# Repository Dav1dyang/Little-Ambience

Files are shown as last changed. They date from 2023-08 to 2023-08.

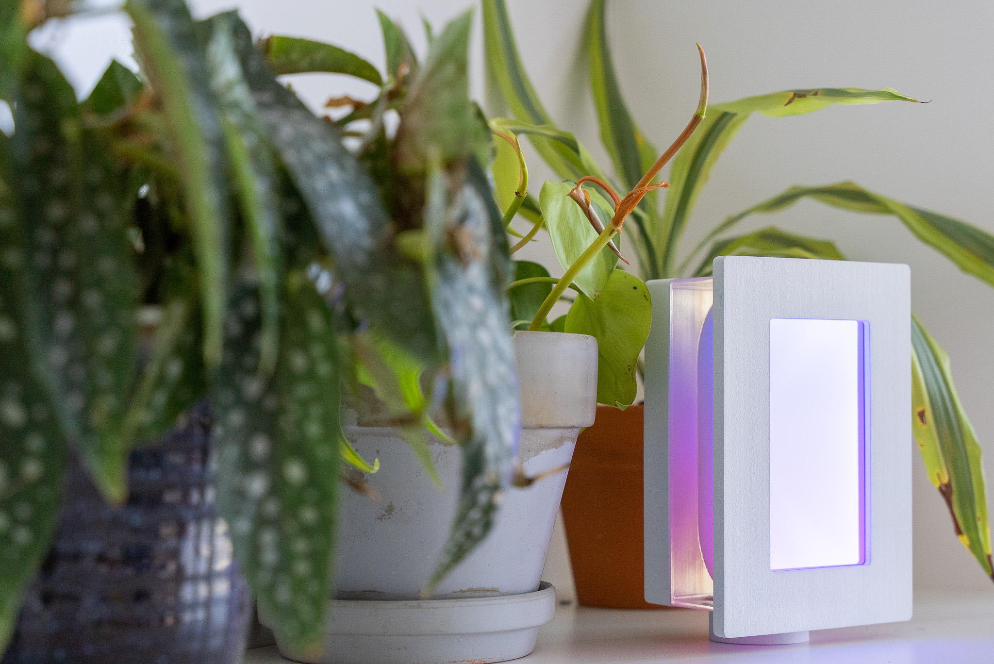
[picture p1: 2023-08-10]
Photos/Product1-Day_and_Night.jpg

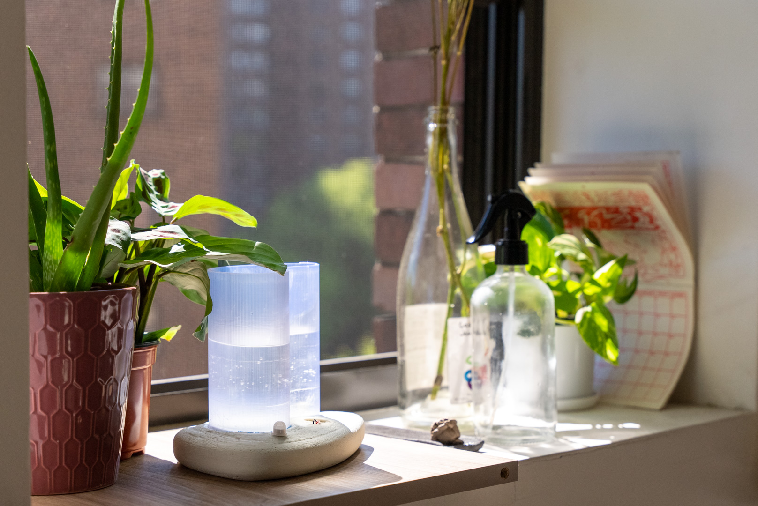
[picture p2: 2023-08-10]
Photos/Water_and_Air_Side.jpg

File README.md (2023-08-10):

# Little Ambience

Tabletop_light

A series of speculative products designed by David Yang. For more information, please visit: https://davidyang.work/Little-Ambience-Detail

## Intro

Little Ambience is a series of speculative household electronics that simulate the remote presence of people and places without relying on video calls. The series comprises two electronics: a tabletop/wall mount light and a pair of humidifiers. The light, designed to resemble a window, displays the sky from a location where people feel connected. The humidifiers are placed in different locations or homes and activate only when both sense the presence of people in the space.

Little Ambience takes the simulation of nature and senses, such as light and smell, to gently decorate a living space with a presence of a place or a person we care about and love. Mirroring the form it takes, Little Ambience interacts passively.

The form is inspired by Taiwanese architectural textures such as pressed windows and Terrazzo, as well as the space and light sculptures made by James Turrell.

## Code

The code is only for functionality testing. It is made specifically to run on ESP32 and a custom PCB.

Right now, the code provided will be able to test out the gradient lights function for the Day & Night light and the mist trigger for the Water & Air humidifier. A few critical steps still need to be taken for it actually to work (Looking for developers to collab!).

Here are the functions list:

### Day and Night (TableTop Light)

| Function | Done? |
| --- | ----- |
| Gradient Color Test | Yes |
| 24 hours sky color test | No |
| ESP32 WIFI Connection | No |
| Weather API Integration | No |
| Weather Animations | No |
| Audio Intergration | No |
| Backend Server | No |

### Water and Air (Humidifier)

| Function | Done? |
| --- | ----- |
| Mist Trigger Test | Yes |
| PIR Sensor Test | No |
| ESP32 WIFI Connection | No |
| Backend server | No |

I used chroma.js with glitch to host a simple server to generate gradient values: https://glitch.com/edit/#!/little-ambience-server

## Little Ambience PCB V1.1

This PCB design utilizes its small footprint to fit into the product. It uses JST connectors for NeoPixels and Lipo Battery. It has USB Mirco for charging.

## Next Steps

I will work on this project's code as much as I can. But I would love to seek help from a professional coder. Moreover, I want to set up live cameras pointing at the sky and find a way to map the sky to Day and Night light.

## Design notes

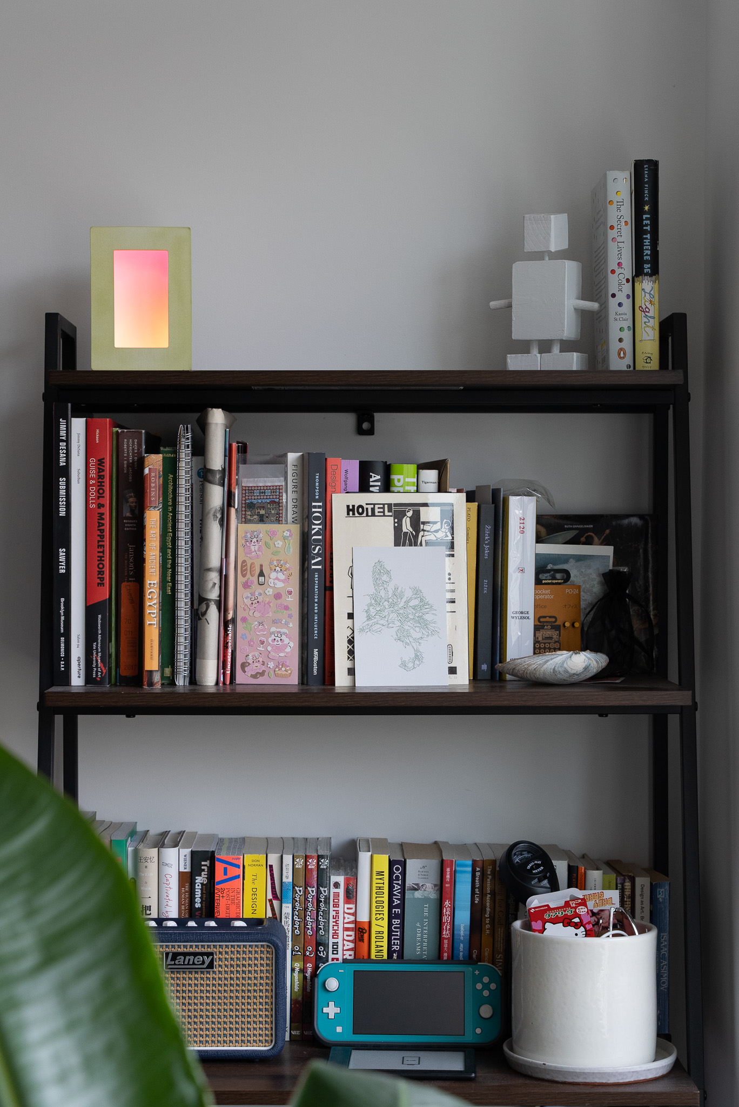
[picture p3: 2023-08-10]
Photos/Day_and_Night_Green_Front.jpg

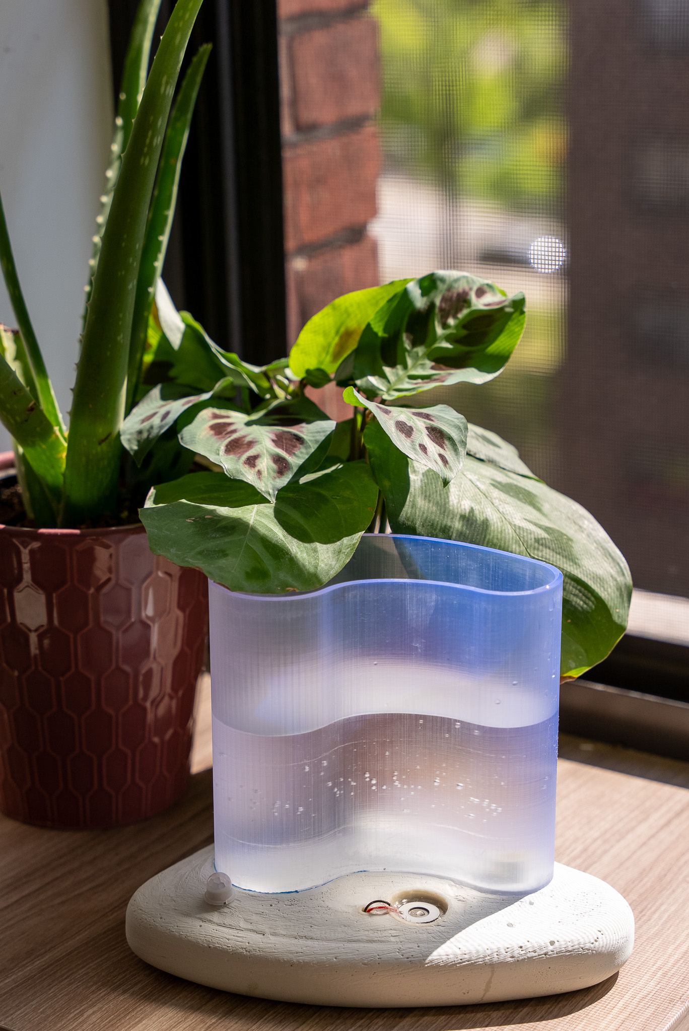
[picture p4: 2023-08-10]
Photos/Product2-Water_and_Air.jpg

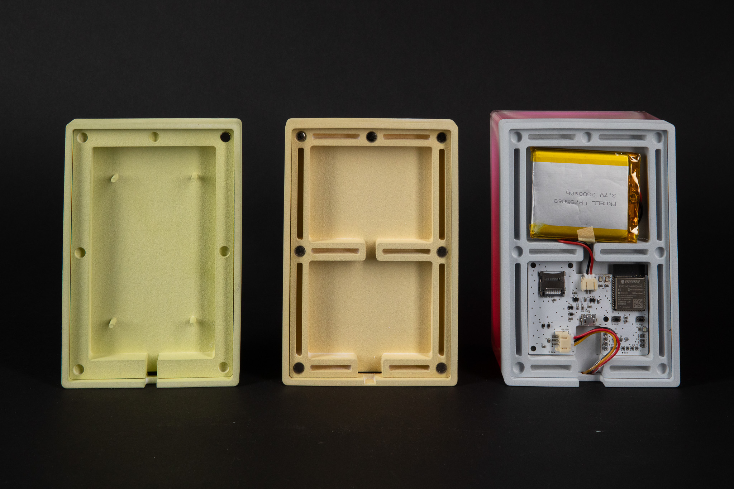
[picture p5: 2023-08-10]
Photos/Day_and_Night_Process_Back.jpg

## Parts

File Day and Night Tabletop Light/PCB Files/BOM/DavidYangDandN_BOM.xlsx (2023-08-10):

Comment | Designator | Footprint | JLCPCB Part #（optional）
0.1uf | C3 | CAPC1608X85 | C386152
10118192-0001LF | USB_MICRO | 10118192-0001LF | C132564
10K | R5, R8, R15, R16 | RESC1608X60 | C227439
10uf | C2, C4 | CAPC1608X85 | C307460
1A/23V/620mV | D2 | SOD-323 | C155590
1uf | C1, C8 | CAPC1608X85 | C106858
2.0k | R2 | RESC1608X60 | C160602
2.2uf | C9 | CAPC1608X85 | C92760
20V/4.2A/52mΩ/1.4W | Q1 | SOT23-3 | C150470
3.3V | IC3 | SOT23-5 | C3021085
470 Ohm | R3, R4, R6, R7 | RESC1608X60 | C175657
5.1K | R1 | RESC1608X60 | C218090
560K | R9 | RESC1608X60 | C137699
AO3406-HT | Q2 | SOT95P280X125-3N | C88051
ESP32-S3-WROOM-1-N8R8 | IC1 | ESP32S3WROOM1N8R8 | C2913201
HYC39-TF08-180 | MICROSD_READER | HYC39TF08180 | C341095
IC_LIPO_CHARGER | IC2 | SOT23-5 | C424093
KMR221NGLFS | S1_BOOT, S2_RESET | KMR221NGLFS | C269272
LTST-C170KFKT | LED1, LED_DONE | LEDC2012X120N | C284931
LTST-C170TBKT | LED_CHARGE | LEDC2012X120N | C98222
PMEG2020AEA,115 | D1, D3 | SOD2512X110N | C389354
S2B-PH-SM4-TB_LF__SN_ | CN2_BAT | S2BPHSM4TBLFSN | C295747
S3B-PH-SM4-TB_LF__SN_ | CN1_NEO | S3B-PH-SM4-TB | C265101

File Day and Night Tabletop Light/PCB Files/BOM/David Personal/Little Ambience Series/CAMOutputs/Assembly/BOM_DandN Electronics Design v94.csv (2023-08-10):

Qty | Value | Device | Package | Parts | Description | ARROW_PART_NUMBER | ARROW_PRICE-STOCK | CATEGORY | DESCRIPTION | HEIGHT | MANUFACTURER | MANUFACTURER_NAME | MANUFACTURER_PART_NUMBER | MOUSER_PART_NUMBER | MOUSER_PRICE-STOCK | MPN | OPERATING_TEMP | PART_STATUS | PROD_ID | RATING | ROHS_COMPLIANT | SERIES | SUB-CATEGORY | THERMALLOSS | TOLERANCE | TYPE | VALUE | VOLTAGE_RATING
1 |  | CONN_02 | 1X02 | CN4_SWITCH | Multi connection point. Often used as Generic Header-pin footprint for 0.1 inch spaced/style header connections
1 |  | CONN_03LONGPADS | 1X03_LONGPADS | CN5_POWER | Multi connection point. Often used as Generic Header-pin footprint for 0.1 inch spaced/style header connections
1 |  | CONN_04 | 1X04 | CN6_PIR | Multi connection point. Often used as Generic Header-pin footprint for 0.1 inch spaced/style header connections |  |  |  |  |  |  |  |  |  |  |  |  |  | CONN-09696
1 |  | CONN_05 | 1X05 | CN3_I2S | Multi connection point. Often used as Generic Header-pin footprint for 0.1 inch spaced/style header connections
1 | 0.1uf | C_CHIP-0603(1608-METRIC) | CAPC1608X85 | C3 | Capacitor - Generic |  |  | Capacitor
1 | 10118192-0001LF | 10118192-0001LF | 10118192-0001LF | USB_MICRO | USB - micro B USB 2.0 Receptacle Connector 5 Position Surface Mount, Right Angle |  |  |  | USB - micro B USB 2.0 Receptacle Connector 5 Position Surface Mount | Right Angle | mm |  | Digi-Key Electronics | 10118192-0001LF
4 | 10K | R_CHIP-0603(1608-METRIC) | RESC1608X60 | R5, R8, R15, R16 | Resistor Fixed - Generic |  |  | Resistor |  |  |  |  |  |  |  |  |  |  |  |  |  |  | Fixed
2 | 10uf | C_CHIP-0603(1608-METRIC) | CAPC1608X85 | C2, C4 | Capacitor - Generic |  |  | Capacitor
1 | 1A/23V/620mV | DIODE-SCHOTTKY-BAT20J | SOD-323 | D2 | Schottky diode |  |  |  |  |  |  |  |  |  |  |  |  |  | DIO-11623 |  |  |  |  |  |  |  | 1A/23V/620mV
2 | 1uf | C_CHIP-0603(1608-METRIC) | CAPC1608X85 | C1, C8 | Capacitor - Generic |  |  | Capacitor
1 | 2.0k | R_CHIP-0603(1608-METRIC) | RESC1608X60 | R2 | Resistor Fixed - Generic |  |  | Resistor |  |  |  |  |  |  |  |  |  |  |  |  |  |  | Fixed
1 | 2.2uf | C_CHIP-0603(1608-METRIC) | CAPC1608X85 | C9 | Capacitor - Generic |  |  | Capacitor
1 | 20V/4.2A/52mΩ/1.4W | MOSFET_PCH-DMG2305UX-7 | SOT23-3 | Q1 | P-channel MOSFETs |  |  |  |  |  |  |  |  |  |  |  |  |  | TRAN-14388 |  |  |  |  |  |  |  | 20V/4.2A/52mΩ/1.4W
1 | 3.3V | V_REG_AP2112K-3.3V | SOT23-5 | IC3 | AP2112 - 600mA CMOS LDO Regulator w/ Enable |  |  |  |  |  |  |  |  |  |  |  |  |  | VREG-12457 |  |  |  |  |  |  |  | 3.3V
4 | 470 Ohm | R_CHIP-0603(1608-METRIC) | RESC1608X60 | R3, R4, R6, R7 | Resistor Fixed - Generic |  |  | Resistor |  |  |  |  |  |  |  |  |  |  |  |  |  |  | Fixed
1 | 5.1K | R_CHIP-0603(1608-METRIC) | RESC1608X60 | R1 | Resistor Fixed - Generic |  |  | Resistor |  |  |  |  |  |  |  |  |  |  |  |  |  |  | Fixed
1 | 560K | R_CHIP-0603(1608-METRIC) | RESC1608X60 | R9 | Resistor Fixed - Generic |  |  | Resistor |  |  |  |  |  |  |  |  |  |  |  |  |  |  | Fixed
1 | AO3406-HT | AO3406-HT | SOT95P280X125-3N | Q2 | 30V N-Channel MOSFET |  |  |  | 30V N-Channel MOSFET | 1.25mm |  | Alpha & Omega Semiconductors | AO3406-HT
1 | ESP32-S3-WROOM-1-N8R8 | ESP32-S3-WROOM-1-N8R8 | ESP32S3WROOM1N8R8 | IC1 | WiFi Modules - 802.11 (Engineering Samples Only) SMD Module, ESP32-S3R8 with 8 MB Octal PSRAM Die, 8 MB Quad SPI flash, PCB Antenna |  |  |  | WiFi Modules - 802.11 (Engineering Samples Only) SMD Module | ESP32-S3R8 with 8 MB Octal PSRAM Die | 8 MB Quad SPI flash | PCB Antenna | 3.25mm |  | Espressif Systems | ESP32-S3-WROOM-1-N8R8 | 356-EP32S3WROOM1N8R8 | https://www.mouser.co.uk/ProductDetail/Espressif-Systems/ESP32-S3-WROOM-1-N8R8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
1 | HYC39-TF08-180 | HYC39-TF08-180 | HYC39TF08180 | MICROSD_READER | Connector SIM CardSD Memory Card 8 SMD Card Sockets Connectors ROHS |  |  |  | Connector SIM CardSD Memory Card 8 SMD Card Sockets Connectors ROHS | 2.1mm |  | HOAUC | HYC39-TF08-180
1 | IC_LIPO_CHARGER | IC_LIPO_CHARGER | SOT23-5 | IC2 | MCP73831/2: LiPo Battery Charger
2 | KMR221NGLFS | KMR221NGLFS | KMR221NGLFS | S1_BOOT, S2_RESET | KMR221NGLFS (Tactile Switches) |  |  |  | KMR221NGLFS (Tactile Switches) | 1.9mm |  | C & K COMPONENTS | KMR221NGLFS | 611-KMR221NGLFS | https://www.mouser.co.uk/ProductDetail/CK/KMR221NGLFS?qs=sb%252But3Lm4x2H4qewmcuXNA%3D%3D
2 | LTST-C170KFKT | LTST-C170KFKT | LEDC2012X120N | LED1, LED_DONE | Standard LEDs - SMD Orange Clear 605nm | LTST-C170KFKT | https://www.arrow.com/en/products/ltst-c170kfkt/lite-on-technology?region=nac |  | Standard LEDs - SMD Orange Clear 605nm | 1.2mm |  | Lite-On | LTST-C170KFKT | 859-LTST-C170KFKT | https://www.mouser.co.uk/ProductDetail/Lite-On/LTST-C170KFKT?qs=gKd32bbgGM%2FWUWN9MKaKoA%3D%3D
1 | LTST-C170TBKT | LTST-C170TBKT | LEDC2012X120N | LED_CHARGE | LED,SMD,0805,Blue,28mcd,130deg | LTST-C170TBKT | https://www.arrow.com/en/products/ltst-c170tbkt/lite-on-technology?region=nac |  | LED | SMD | 0805 | Blue | 28mcd | 130deg | 1.2mm |  | Lite-On | LTST-C170TBKT | 859-LTST-C170TBKT | https://www.mouser.co.uk/ProductDetail/Lite-On/LTST-C170TBKT?qs=0uL0gcxEMop2ooGmIUzw3A%3D%3D
2 | PMEG2020AEA,115 | PMEG2020AEA,115 | SOD2512X110N | D1, D3 | NXP PMEG2020AEA,115, SMT Schottky Diode, 20V 2A, 2-Pin SOD-323 | PMEG2020AEA | 115 | https://www.arrow.com/en/products/pmeg2020aea115/nexperia?region=nac |  | NXP PMEG2020AEA | 115 | SMT Schottky Diode | 20V 2A | 2-Pin SOD-323 | 1.1mm |  | Nexperia | PMEG2020AEA | 115 | 771-PMEG2020AEA-T/R | https://www.mouser.co.uk/ProductDetail/Nexperia/PMEG2020AEA115?qs=LOCUfHb8d9vXteLLZxwsEQ%3D%3D
1 | S2B-PH-SM4-TB_LF__SN_ | S2B-PH-SM4-TB_LF__SN_ | S2BPHSM4TBLFSN | CN2_BAT | Conn Shrouded Header (4 Sides) HDR 2 POS 2mm Solder RA Side Entry SMD T/R | S2B-PH-SM4-TB(LF)(SN) | https://www.arrow.com/en/products/s2b-ph-sm4-tb-lf-sn/jst-manufacturing?region=europe |  | Conn Shrouded Header (4 Sides) HDR 2 POS 2mm Solder RA Side Entry SMD T/R | 6.6mm |  | JST (JAPAN SOLDERLESS TERMINALS) | S2B-PH-SM4-TB(LF)(SN)
1 | S3B-PH-SM4-TB_LF__SN_ | S3B-PH-SM4-TB_LF__SN_ | S3B-PH-SM4-TB | CN1_NEO | PH SMT side entry shroud header 3 way JST PH Series, 2mm Pitch 3 Way 1 Row Right Angle PCB Header, Solder Termination, 2A | S3B-PH-SM4-TB(LF)(SN) | https://www.arrow.com/en/products/s3b-ph-sm4-tb-lf-sn/jst-manufacturing?region=europe |  | PH SMT side entry shroud header 3 way JST PH Series | 2mm Pitch 3 Way 1 Row Right Angle PCB Header | Solder Termination | 2A | mm |  | JST (JAPAN SOLDERLESS TERMINALS) | S3B-PH-SM4-TB(LF)(SN)

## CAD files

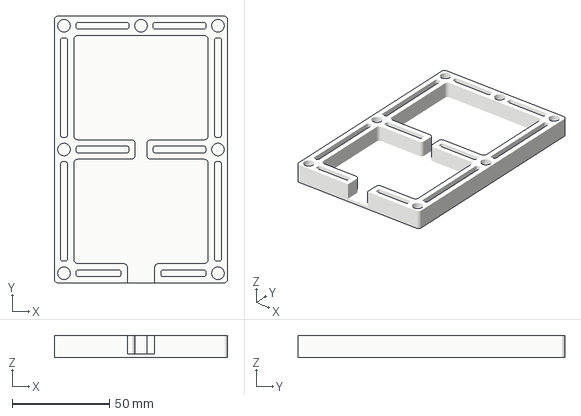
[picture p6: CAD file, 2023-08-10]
Day and Night Tabletop Light/3D Prints/DandN Version 4_Back_Panel.3mf
89.0 x 137.0 x 11.4 mm

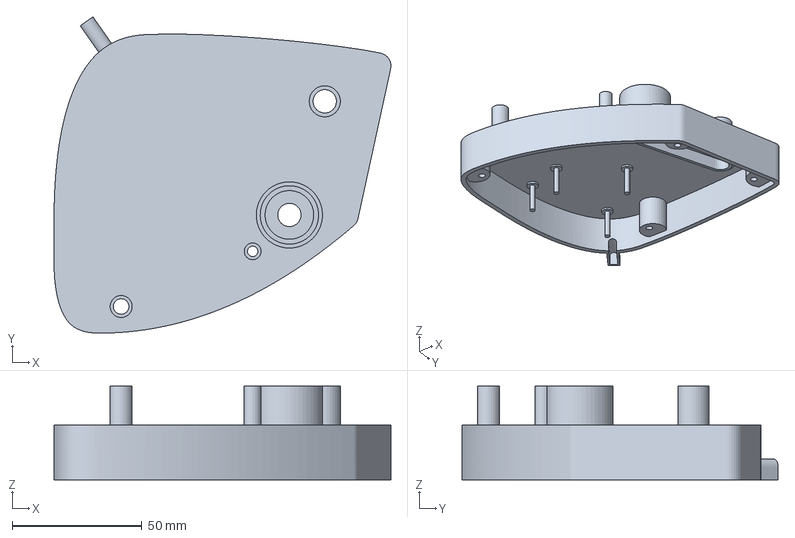
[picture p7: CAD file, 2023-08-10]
Water and Air/3D Print/Mold/Misty Pond Version 1_interior_Box v1.3mf
129.8 x 121.8 x 36.0 mm

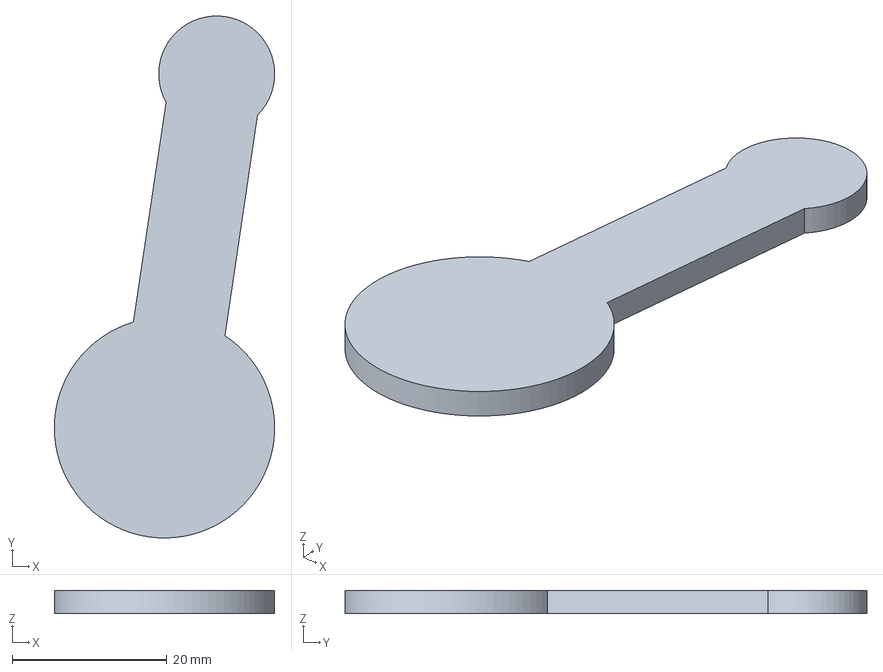
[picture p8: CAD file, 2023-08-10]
Water and Air/3D Print/Positive/Misty Pond Version 1_StandWaterWay_Offwhite v2.3mf
28.5 x 67.5 x 3.00 mm

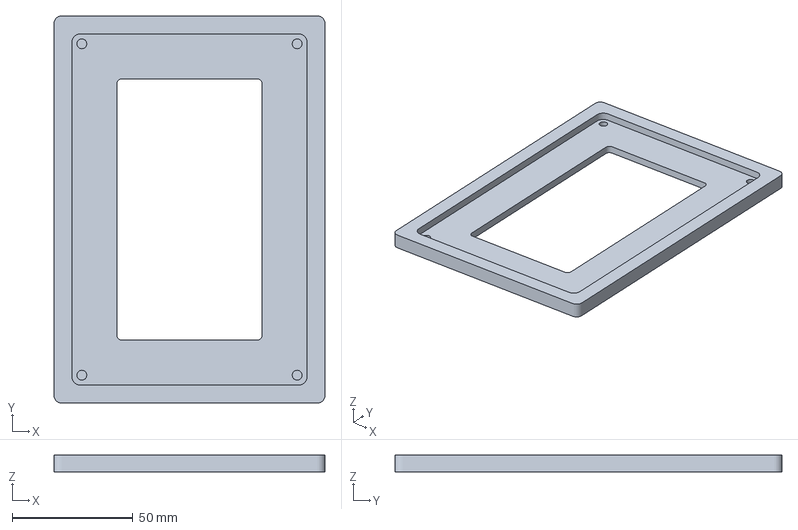
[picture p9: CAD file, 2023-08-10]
Day and Night Tabletop Light/3D Prints/DandN Version 4_Front_Frame_Base.3mf
112.0 x 160.0 x 7.00 mm

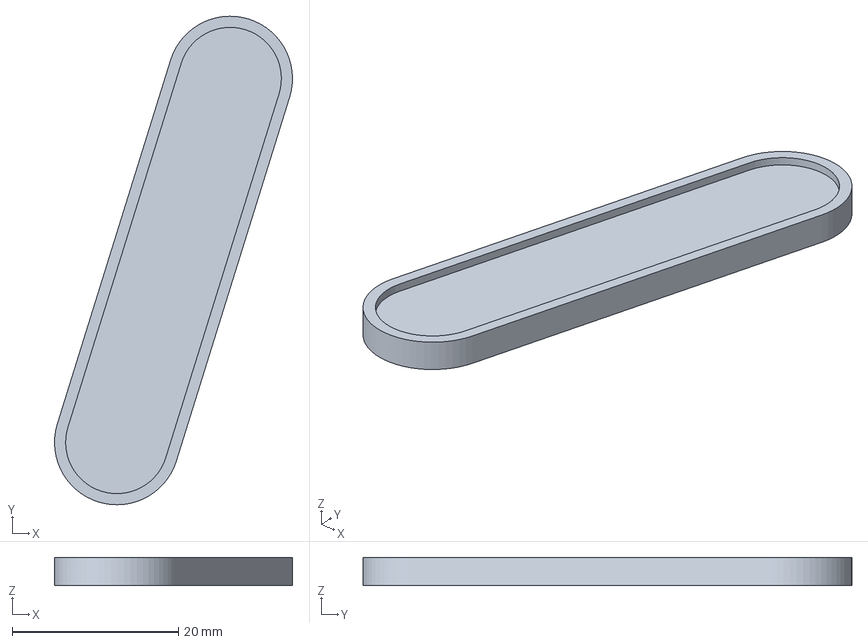
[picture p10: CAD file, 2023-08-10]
Water and Air/3D Print/Mold/Misty Pond Version 1_Waterway_Cap v1.3mf
28.6 x 58.7 x 3.40 mm

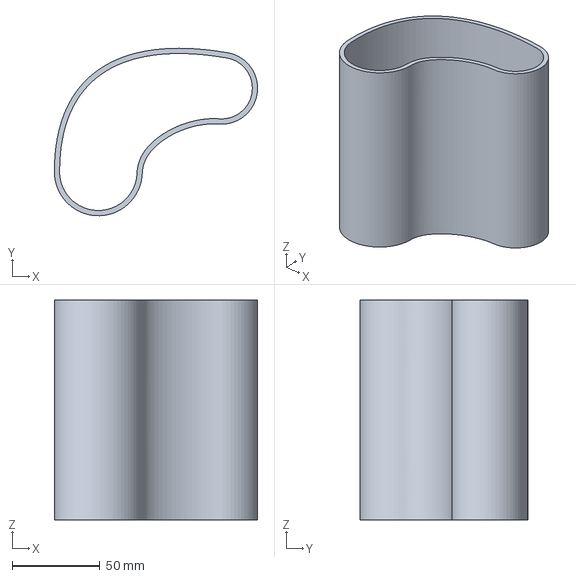
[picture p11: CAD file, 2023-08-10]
Water and Air/3D Print/Positive/Misty Pond Version 1_Pond_Clear v2.3mf
115.5 x 95.2 x 125.0 mm

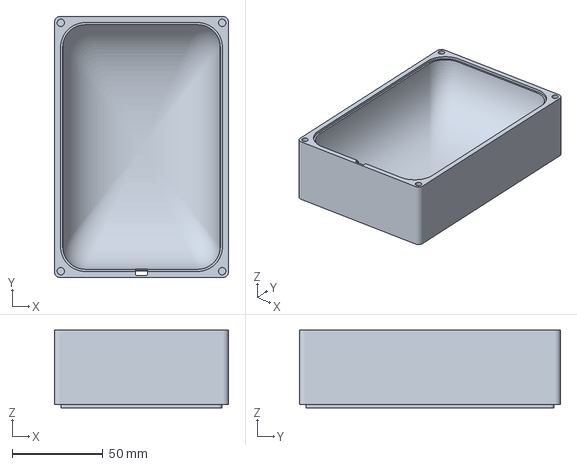
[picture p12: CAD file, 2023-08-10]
Day and Night Tabletop Light/3D Prints/DandN Version 4_Resin_Shell_Cutout.3mf
96.0 x 144.0 x 43.0 mm

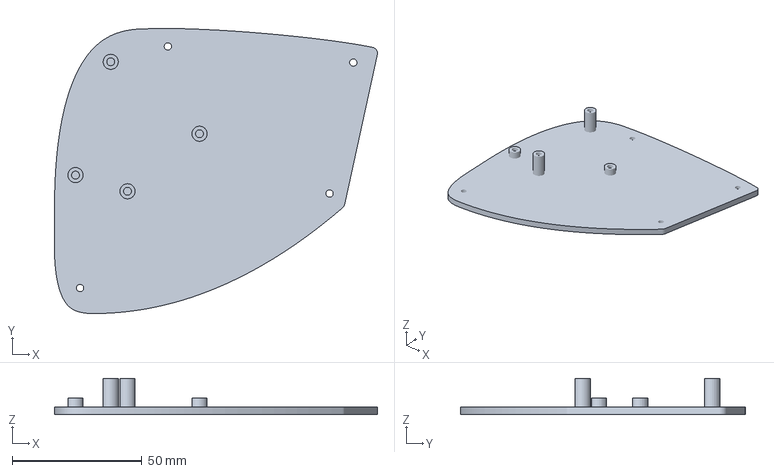
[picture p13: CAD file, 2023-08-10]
Water and Air/3D Print/Mold/Misty Pond Version 1_Box_Cover v1.3mf
124.4 x 109.8 x 14.0 mm

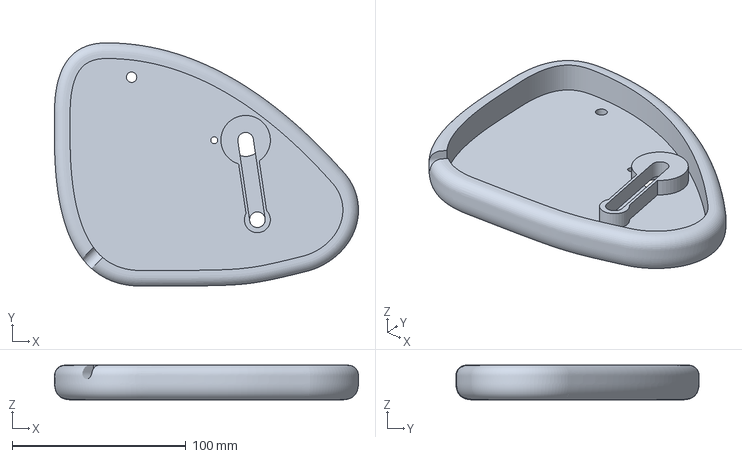
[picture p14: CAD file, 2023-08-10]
Water and Air/3D Print/Positive/Misty Pond Version 1_Stand_OffWhite v2.3mf
174.9 x 140.0 x 20.0 mm

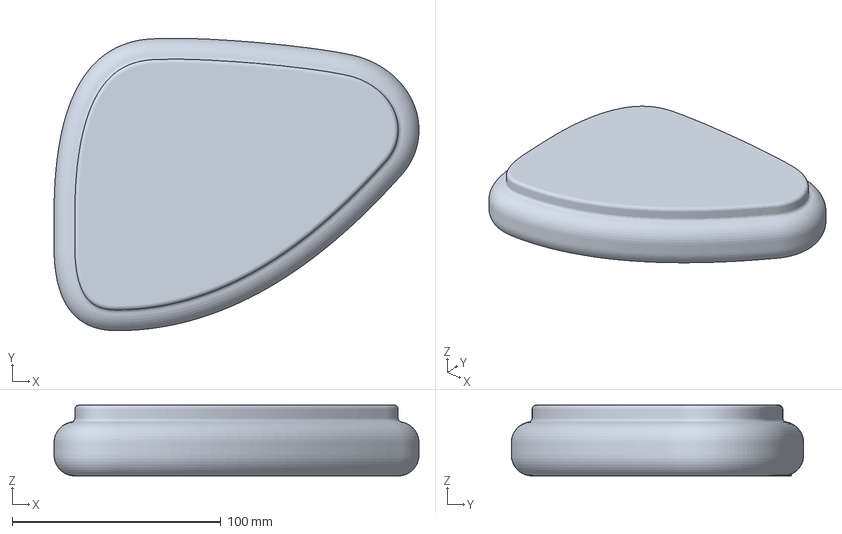
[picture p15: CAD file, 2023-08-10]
Water and Air/3D Print/Mold/Misty Pond Version 1_Mold v1.3mf
174.9 x 140.2 x 34.0 mm

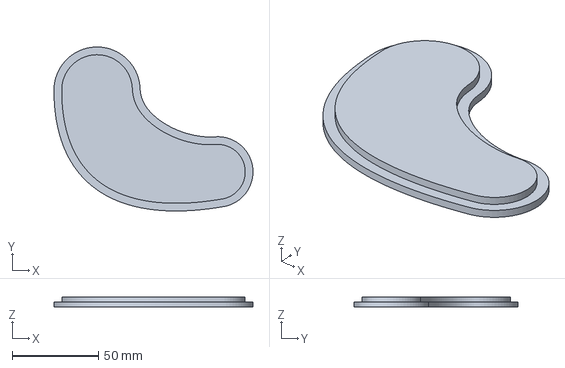
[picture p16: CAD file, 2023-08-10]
Water and Air/3D Print/Positive/Misty Pond Version 1_PondCap_Offwhite v2.3mf
115.5 x 95.2 x 6.00 mm

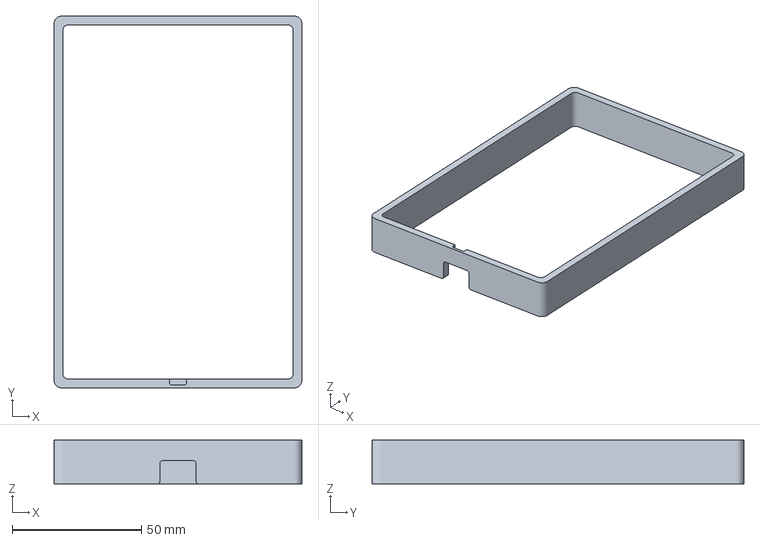
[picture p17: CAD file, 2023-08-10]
Day and Night Tabletop Light/3D Prints/D&N Version 4_Back_Frame.3mf
96.0 x 144.0 x 17.0 mm

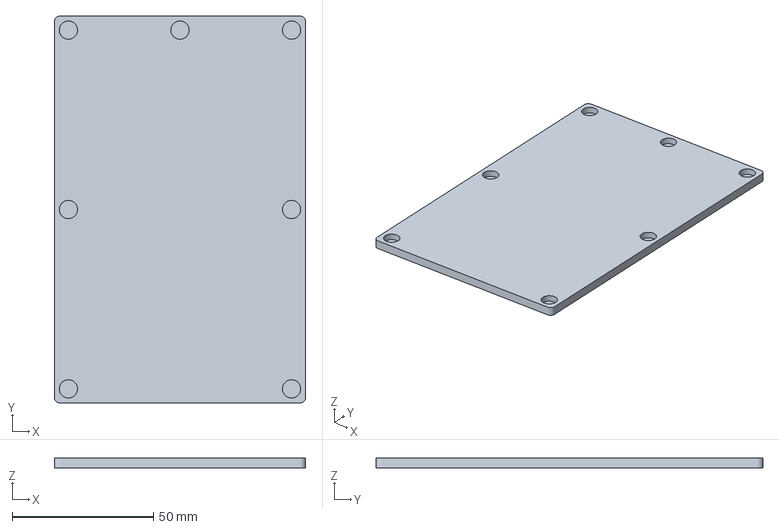
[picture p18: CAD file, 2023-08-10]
Day and Night Tabletop Light/3D Prints/DandN Version 4_Back_Lid.3mf
89.0 x 137.0 x 3.50 mm

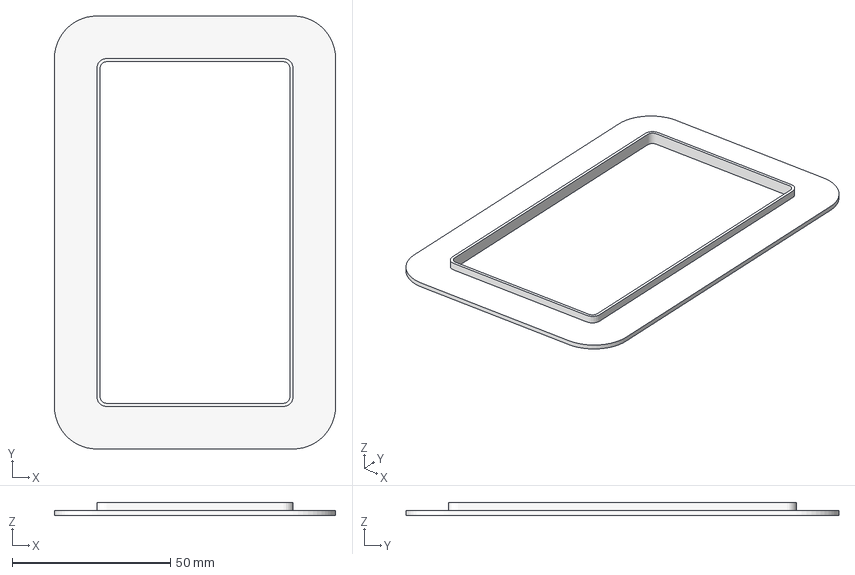
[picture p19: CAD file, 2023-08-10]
Day and Night Tabletop Light/3D Prints/DandN Version 4_NeoPixel_Panel.3mf
88.9 x 136.9 x 4.00 mm

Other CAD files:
Day and Night Tabletop Light/3D Prints/DandN Version 4_Resin_Shell_No_cutout.3mf
Day and Night Tabletop Light/3D Prints/DandN Version 4_Stand.3mf

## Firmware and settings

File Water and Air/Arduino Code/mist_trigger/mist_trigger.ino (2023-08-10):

/*
  Blink

  Turns an LED on for one second, then off for one second, repeatedly.

  Most Arduinos have an on-board LED you can control. On the UNO, MEGA and ZERO
  it is attached to digital pin 13, on MKR1000 on pin 6. LED_BUILTIN is set to
  the correct LED pin independent of which board is used.
  If you want to know what pin the on-board LED is connected to on your Arduino
  model, check the Technical Specs of your board at:
  https://www.arduino.cc/en/Main/Products

  modified 8 May 2014
  by Scott Fitzgerald
  modified 2 Sep 2016
  by Arturo Guadalupi
  modified 8 Sep 2016
  by Colby Newman

  This example code is in the public domain.

  https://www.arduino.cc/en/Tutorial/BuiltInExamples/Blink
*/

// the setup function runs once when you press reset or power the board

bool mistSwitch = false;

void setup() {
  // initialize digital pin LED_BUILTIN as an output.
  pinMode(45, OUTPUT);
  pinMode(42, OUTPUT);
  digitalWrite(45, LOW);
}

// the loop function runs over and over again forever
void loop() {

  if (mistSwitch == false) {
    digitalWrite(45, HIGH);
    delay(100);
    digitalWrite(45, LOW);
    digitalWrite(42, HIGH);
    mistSwitch = true;
    delay(100000);
  } else {
    digitalWrite(45, HIGH);
    delay(100);
    digitalWrite(45, LOW);
    digitalWrite(42, LOW);
    mistSwitch = false;
    delay(2000);
  }
}

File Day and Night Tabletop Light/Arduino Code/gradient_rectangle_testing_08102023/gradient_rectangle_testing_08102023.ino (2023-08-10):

/*
This code is for creating simple gradient with neopixel strips.
Made with the modification from Adafruit's NeoPixel Library Examples. 
This is definately not the most efficient way code gradient, but it get the job done. For more details, please visit: 

Details about neopixel setup: 
https://learn.adafruit.com/adafruit-neopixel-uberguide/

Created by David Yang with Shirley Wu's Help 03/29/2023
*/

#include <Adafruit_NeoPixel.h>
#ifdef __AVR__
#include <avr/power.h>  // Required for 16 MHz Adafruit Trinket
#endif

// Which pin on the Arduino is connected to the NeoPixels?
#define LED_PIN 38

// How many NeoPixels are attached to the Arduino?
#define LED_COUNT 50

// How many pixels are on the X and Y axis of therectangle?
#define LED_X 9
#define LED_Y 16
#define LED_Height 20
#define LED_Length 12

// How many colors the gradient will cycle through?
#define numColors 120

// Declare our NeoPixel strip object:
Adafruit_NeoPixel strip(LED_COUNT, LED_PIN, NEO_GRB + NEO_KHZ800);
// Argument 1 = Number of pixels in NeoPixel strip
// Argument 2 = Arduino pin number (most are valid)
// Argument 3 = Pixel type flags, add together as needed:
//   NEO_KHZ800  800 KHz bitstream (most NeoPixel products w/WS2812 LEDs)
//   NEO_KHZ400  400 KHz (classic 'v1' (not v2) FLORA pixels, WS2811 drivers)
//   NEO_GRB     Pixels are wired for GRB bitstream (most NeoPixel products)
//   NEO_RGB     Pixels are wired for RGB bitstream (v1 FLORA pixels, not v2)
//   NEO_RGBW    Pixels are wired for RGBW bitstream (NeoPixel RGBW products)

// define the array to storge the pixel position
int top[LED_X] = {};
int right[LED_Y] = {};
int left[LED_Y] = {};
int bottom[LED_X] = {};

int timestep = 0;
// Variables to control the changes in the gradient function
int increment = numColors / LED_Height;  // the increment of each pixels based on the total height on the LED grid

int colorsSunset[numColors][3] = { { 141, 192, 204 }, { 143, 189, 202 }, { 143, 188, 201 }, { 144, 185, 199 }, { 145, 183, 198 }, { 145, 180, 196 }, { 146, 177, 195 }, { 146, 175, 193 }, { 147, 172, 191 }, { 148, 170, 190 }, { 148, 168, 189 }, { 149, 165, 188 }, { 150, 163, 186 }, { 150, 160, 185 }, { 151, 158, 183 }, { 152, 155, 182 }, { 152, 152, 180 }, { 153, 150, 178 }, { 153, 148, 177 }, { 154, 146, 175 }, { 155, 143, 174 }, { 155, 140, 172 }, { 156, 138, 171 }, { 157, 135, 169 }, { 157, 132, 167 }, { 158, 130, 167 }, { 159, 127, 165 }, { 159, 126, 164 }, { 160, 123, 162 }, { 160, 120, 161 }, { 160, 118, 159 }, { 161, 115, 158 }, { 161, 113, 156 }, { 162, 110, 154 }, { 163, 107, 153 }, { 163, 105, 151 }, { 164, 102, 150 }, { 165, 100, 148 }, { 165, 97, 147 }, { 165, 94, 146 }, { 166, 92, 144 }, { 166, 89, 143 }, { 167, 87, 141 }, { 167, 84, 140 }, { 168, 81, 138 }, { 169, 79, 137 }, { 169, 76, 135 }, { 169, 74, 134 }, { 170, 70, 132 }, { 170, 67, 130 }, { 171, 65, 129 }, { 172, 61, 128 }, { 172, 59, 127 }, { 172, 55, 125 }, { 172, 52, 124 }, { 173, 49, 122 }, { 174, 45, 120 }, { 174, 42, 119 }, { 175, 38, 117 }, { 176, 33, 116 }, { 176, 33, 116 }, { 175, 38, 117 }, { 174, 42, 119 }, { 174, 45, 120 }, { 173, 49, 122 }, { 172, 52, 124 }, { 172, 55, 125 }, { 172, 59, 127 }, { 172, 61, 128 }, { 171, 65, 129 }, { 170, 67, 130 }, { 170, 70, 132 }, { 169, 74, 134 }, { 169, 76, 135 }, { 169, 79, 137 }, { 168, 81, 138 }, { 167, 84, 140 }, { 167, 87, 141 }, { 166, 89, 143 }, { 166, 92, 144 }, { 165, 94, 146 }, { 165, 97, 147 }, { 165, 100, 148 }, { 164, 102, 150 }, { 163, 105, 151 }, { 163, 107, 153 }, { 162, 110, 154 }, { 161, 113, 156 }, { 161, 115, 158 }, { 160, 118, 159 }, { 160, 120, 161 }, { 160, 123, 162 }, { 159, 126, 164 }, { 159, 127, 165 }, { 158, 130, 167 }, { 157, 132, 167 }, { 157, 135, 169 }, { 156, 138, 171 }, { 155, 140, 172 }, { 155, 143, 174 }, { 154, 146, 175 }, { 153, 148, 177 }, { 153, 150, 178 }, { 152, 152, 180 }, { 152, 155, 182 }, { 151, 158, 183 }, { 150, 160, 185 }, { 150, 163, 186 }, { 149, 165, 188 }, { 148, 168, 189 }, { 148, 170, 190 }, { 147, 172, 191 }, { 146, 175, 193 }, { 146, 177, 195 }, { 145, 180, 196 }, { 145, 183, 198 }, { 144, 185, 199 }, { 143, 188, 201 }, { 143, 189, 202 }, { 141, 192, 204 } };

// setup() function -- runs once at startup --------------------------------

void setup() {

// leaving this here just in case this is applied to ATTiny85.
// These lines are specifically to support the Adafruit Trinket 5V 16 MHz.
// Any other board, you can remove this part (but no harm leaving it):
#if defined(__AVR_ATtiny85__) && (F_CPU == 16000000)
  clock_prescale_set(clock_div_1);
#endif
  // END of Trinket-specific code.

  strip.begin();            // INITIALIZE NeoPixel strip object (REQUIRED)
  strip.show();             // Turn OFF all pixels ASAP
  strip.setBrightness(30);  // Set BRIGHTNESS to about 1/5 (max = 255)

  // Generate Array for the LED Rectangle Setup - assign pixel positions base on 4 sides of the rect
  for (int xAxisShift = 0; xAxisShift < LED_X; xAxisShift += 1)  //Assigned LED on the x axis
  {
    top[xAxisShift] = LED_Y + xAxisShift;
    bottom[xAxisShift] = LED_Y * 2 + LED_X + xAxisShift;
  }

  for (int yAxisShift = 0; yAxisShift < LED_Y; yAxisShift += 1)  //Assigned LED on the y axis
  {
    right[yAxisShift] = yAxisShift;
    left[yAxisShift] = LED_Y * 2 + LED_X - 1 - yAxisShift;
  }
}

// loop() function -- runs repeatedly as long as board is on ---------------

void loop() {

  gradient(colorsSunset);
  timestep += 1;
  delay(15);
}

// functions for creating animated effects -----------------

void gradient(int colors[numColors][3]) {

  //strip.clear();  // Set all pixel colors to 'off'

  // for each pixel

  // for (int timestep = 0; timestep < numColors; timestep++) { // increased steps in each loop consistantly

  for (int pos = 0; pos < LED_Height; pos++) {

    int colorIndex = (pos * increment + timestep) % numColors; // NEEDS CHANGE
    colorIndex = max(min(colorIndex, numColors), 0); // bound to [0, 120]
    int color = strip.Color(colors[colorIndex][0], colors[colorIndex][1], colors[colorIndex][2]);

    if (pos == 0) {
      for (int pixel = 0; pixel < LED_X; pixel++) {
        strip.setPixelColor(top[pixel], color);
      }
    } else if (pos == 19) {
      for (int pixel = 0; pixel < LED_X; pixel++) {
        strip.setPixelColor(bottom[pixel], color);
      }
    }

    if (pos < LED_Y) {
      strip.setPixelColor(left[pos], color);
      strip.setPixelColor(right[pos], color);
    }

    // }
  }

  strip.show();
}
